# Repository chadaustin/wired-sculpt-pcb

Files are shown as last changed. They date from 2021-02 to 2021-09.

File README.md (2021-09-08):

# Design Files for Wired Sculpt Conversion Board

This repository contains the schematic and layout files for the [Microsoft Sculpt Wired Conversion Mod](https://chadaustin.me/2021/02/wired-sculpt/).

## Project Updates

### 2021-09-07

The rev4 board design is complete.

When I upgraded the 30-pin ribbon connector to one that fit better, it lowered the resistance to the LEDs. This caused me to burn the microcontroller on a test rev3 board by drawing too much current. So the question became: what values are appropriate for "maximum" brightness on both red and green. Today I found that, given a 5.15V VUSB, whatever resistance in the flex cable, and whatever voltage drop on the LEDs, 150 Ohms gives an even brightness on both red and green. Green draws about 15 mA and red about 10 mA, both within USB low-power spec and the current limits on the microcontroller.

I added an [outputs](outputs/) directory containing the different revisions, and gerber files and drill files generated for either PCBWay or OSH Park.

The biggest challenge right now is the chip shortage. Even some of the capacitors I chose are out of stock. The hardest component to acquire is the ESD protection IC: USBLC6-2SC6. The USBLC6-4SC6 is available, but it would require some tweaking to the PCB layout.

On the software side of things, I added an internal ring buffer for debugging the debouncer. It can be dumped to the HID debug channel by holding both shifts and pressing H. I am trying to figure out why, with my custom low-latency debouncer, sometimes "the" comes out as "theb". For anyone that isn't trying to optimize latency as much as me, you can just run with the default QMK debouncer, which I've never seen produce phantom keys.

### 2021-05-02

One thing that annoyed me about the previous board design was that neither LED was hooked up to a PWM-capable pin and that the green one couldn't be driven, since it wants -5V. I want both lights to work and both to be dimmable.

Rev3 includes a charge pump to produce -5V and two MOSFETs that allow switching the green cathode with PWM.

I also figured out how the Fn switch works: it's a resistor divider that toggles 47K pull-down on a pin with a permanent 1M pull-up. Rev3 includes said 1M pull-up, so the firmware can read the Fn switch's state.

Sadly, it looks like there were many arrangements of media keys on the Sculpt over the years, and most of the media keys have nonsensical icons with behavior that differs on each platform. I'll try to make at least volume and play/pause work.

The parts for board rev 3 arrived last week. Some adjustments were required due to the chip shortage, but it's not too bad. The microcontroller is still available at least.

I attempted assembly of one, and it worked fine, but I screwed up the red and green pins, so I cut some traces and bodged in some kynar wire.

Both lights work!

I have not tested PWM. I did observe that twice as much current is being drawn for each light as I expected. I fear 40 mA could burn out the lights, so I plan to measure an appropriate series resistor this week. It's possible I never had this problem before because I was using a worse-fitting ribbon connector previously. In the past, I always measured 100 Ohms on every pin, but never tested the new ribbon connector.

Also, it kind of sucks that the LED brightness is a function of USB voltage (anywhere between 4.6 V and 5.25 V), but I don't want to include a regulator...

Assembly took about five hours for one board. A lot of that was getting my desk set up. I imagine I could do three boards in ... eight? I think if I used a stencil, hot air assembly could go pretty quickly. Especially if I had a preheater like the MHP30.

A couple people have suggested I set up an Etsy, but if I properly priced in hours of my labor, it would get prohibitive. And I don't want to deal with returns and warranties.

Remaining items before I can say the board is done:
* Order a fourth PCB design with fixed green and red pins
* Include an 0603 resistor on each
* Fix the debouncer
* Add a media key QMK layer, enabled with the Fn switch.

### 2021-04-27

In February, I tried pushing latency further than QMK offers out of the box. I switched from the default debouncer to sym_eager_pk, but since then I've observed some false keydowns and occasionally a phantom keypress. It's common for "the" to produce "theb". (Note that I use the Dvorak key layout.) I haven't looked at the matrix, but it's clear some debouncing is needed on keydown.

I'm planning on writing a custom debouncer that requires at least two frames for a keydown to register and at least 10 ms for a keyup. Having never done AVR optimization, I am trying to get a [simavr](https://github.com/buserror/simavr) benchmark harness up to make sure I don't regress the scan rate.

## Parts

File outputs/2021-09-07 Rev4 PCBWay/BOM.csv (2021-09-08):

Component | Description | Part | References | Value | Footprint | Quantity Per PCB | Datasheet | Notes
1 | Unpolarized capacitor | C | C4 C5 C6 C9 | CL10A105KA8NNNC | C_0603_1608Metric | 4 | ~
2 | Unpolarized capacitor | C | C10 C11 C12 | CL10B104KB8NNNC | C_0603_1608Metric | 3 | https://media.digikey.com/pdf/Data%20Sheets/Samsung%20PDFs/CL05A104KA5NNNC.pdf
3 | Unpolarized capacitor | C | C7 C8 | CL10C160JB8NNNC | C_0603_1608Metric | 2 | ~
4 | Unpolarized capacitor | C | C1 | CL21A475KOFNNNE | C_0805_2012Metric | 1 | ~
5 | Unpolarized capacitor | C | C3 | CL21B103KBANNNC | C_0805_2012Metric | 1 | ~
6 | Unpolarized capacitor | C | C2 | CL21B104KACNNNC | C_0805_2012Metric | 1 | ~
7 | Light emitting diode | LED | D1 | 150080GS75000 | LED_0603_1608Metric_Castellated | 1 | ~
8 | USB Micro Type B connector | USB_B_Micro | J1 | 10103594-0001LF | USB_Micro-B_Amphenol_10103594-0001LF_Horizontal | 1 | https://www.amphenol-icc.com/media/wysiwyg/files/drawing/10118193.pdf
10 | Generic connector, single row, 01x30, script generated (kicad-library-utils/schlib/autogen/connector/) | Conn_01x30_Female | J2 | FFC3B07-30-T | TE_3-84952-0_1x30-1MP_P1.0mm_Horizontal | 1 | https://gct.co/files/specs/1.0mm-ffc-spec.pdf
11 | 0.115A Id, 60V Vds, N-Channel MOSFET, SOT-23 | 2N7002 | Q2 | 2N7002BK | SOT-23 | 1 | https://assets.nexperia.com/documents/data-sheet/2N7002BK.pdf
12 | -0.13A Id, -50V Vds, P-Channel MOSFET, SOT-23 | BSS84 | Q1 | BSS84AK,215 | SOT-23 | 1 | https://assets.nexperia.com/documents/data-sheet/BSS84AK.pdf
13 | Resistor, US symbol | R_US | R4 | ERJ-3EKF8873V | R_0603_1608Metric | 1 | ~
14 | Resistor, US symbol | R_US | R6 R9 R10 | ERJ-3GEYJ331V | R_0603_1608Metric | 3 | ~
15 | Resistor, US symbol | R_US | R1 R2 R7 | ERJ-PA3F22R0V | R_0603_1608Metric | 3 | ~
16 | Resistor, US symbol | R_US | R11 R12 | ERJ-PA3J151V | R_0603_1608Metric | 2 | ~ | Allows 10 mA. Maybe 100R would be fine. Measures at 15-17 mA.
17 | Resistor, US symbol | R_US | R3 R8 | ERJ-PA3J472V | R_0603_1608Metric | 2
18 | Resistor, US symbol | R_US | R5 | ERJ-PA3J473V | R_0603_1608Metric | 1 | ~
19 | Push button switch, generic, two pins | SW_Push | SW1 | FSMSM | SW_SPST_FSMSM | 1 | ~
20 | Generic connector, single row, 01x02, script generated (kicad-library-utils/schlib/autogen/connector/) | Conn_01x02_Female | SW2 | S2B-PH-K-S(LF)(SN) | JST_PH_S2B-PH-K_1x02_P2.00mm_Horizontal | 1 | https://www.jst-mfg.com/product/pdf/eng/ePH.pdf
21 | 16MHz, 128kB Flash, 8kB SRAM, 4kB EEPROM, USB 2.0, TQFP-64 | AT90USB1286-AU | U3 | AT90USB1286-AU | TQFP-64_14x14mm_P0.8mm | 1 | http://ww1.microchip.com/downloads/en/DeviceDoc/doc7593.pdf
22 | Switched capacitor inverter, inverts positive voltage +2.7 to +5.5V to negative, 200mA, SOT-23-6 | LM2776 | U2 | LM2776DBVT | SOT-23-6 | 1 | http://www.ti.com/lit/ds/symlink/lm2776.pdf
23 | Very low capacitance ESD protection diode, 2 data-line, SOT-23-6 | USBLC6-2SC6 | U1 | USBLC6-2SC6 | SOT-23-6 | 1 | https://www.st.com/resource/en/datasheet/usblc6-2.pdf
24 | Four pin crystal, GND on pins 2 and 4 | Crystal_GND24 | Y1 | TSX-3225 16.0000MF18X-AC0 | Crystal_SMD_3225-4Pin_3.2x2.5mm | 1 | https://www5.epsondevice.com/en/information/support/pdf/june_2018_psc_masterbook.pdf
Component Groups: | 24
Component Count: | 36
Fitted Components: | 36
Number of PCBs: | 1
Total components: | 36
Schematic Version:
Schematic Date:
PCB Variant: | udefault
BoM Date: | 2021-09-07 17:42
Schematic Source: | wired-sculpt.sch
KiCad Version: | Eeschema (5.1.8)-1

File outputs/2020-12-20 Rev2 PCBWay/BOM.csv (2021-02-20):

Id | Designator | Package | Quantity | Part # | Manufacturer | Notes
1 | U1 | TQFP-64_14x14mm_P0.8mm | 1 | AT90USB1286-AU | Atmel | Align dot on chip with dot on PCB (pin 1)
2 | J3 | IDC-Header_2x03_P2.54mm_Vertical | 1 | NOT FITTED
3 | R1,R3 | R_0603_1608Metric | 2 | ERJ-PA3F22R0V | Panasonic
4 | J4 | TE_3-84952-0_1x30-1MP_P1.0mm_Horizontal | 1 | 3-84952-0 | TE Connectivity
5 | C2,C3 | C_0603_1608Metric | 2 | 06035A160JAT2A | AVX Corporation
6 | C4 | C_0603_1608Metric | 1 | C0603C105K4RACTU | KEMET
7 | D1 | LED_0603_1608Metric_Castellated | 1 | 150080GS75000 | Wurth Electronik
8 | J1 | USB_Micro-B_Amphenol_10103594-0001LF_Horizontal | 1 | 10103594-0001LF | Amphenol ICC
9 | R2 | R_0603_1608Metric | 1 | ERJ-3EKF2200V | Panasonic
10 | R4,R5,R6 | R_0603_1608Metric | 3 | ERJ-3GEYJ331V | Panasonic
11 | SW1 | SW_SPST_FSMSM | 1 | FSMSM | TE Connectivity
12 | Y1 | Crystal_SMD_3225-4Pin_3.2x2.5mm | 1 | TSX-3225 16.0000MF18X-AC6 | Epson
13 | R8 | R_0603_1608Metric | 1 | ERJ-3EKF1001V | Panasonic
16 | C1 | C_1206_3216Metric | 1 | TAJA106K006RNJ | AVX Corporation
17 | C6,C7,C5 | C_0402_1005Metric | 3 | CL05A104KA5NNNC | Samsung
18 | R9 | R_0603_1608Metric | 1 | ERJ-3GEYJ331V | Panasonic
19 | U2 | SOT-23-6 | 1 | USBLC6-2SC6 | STMicroelectronics | Pin 1 is aligned with longer line on silkscreen, towards outside of board

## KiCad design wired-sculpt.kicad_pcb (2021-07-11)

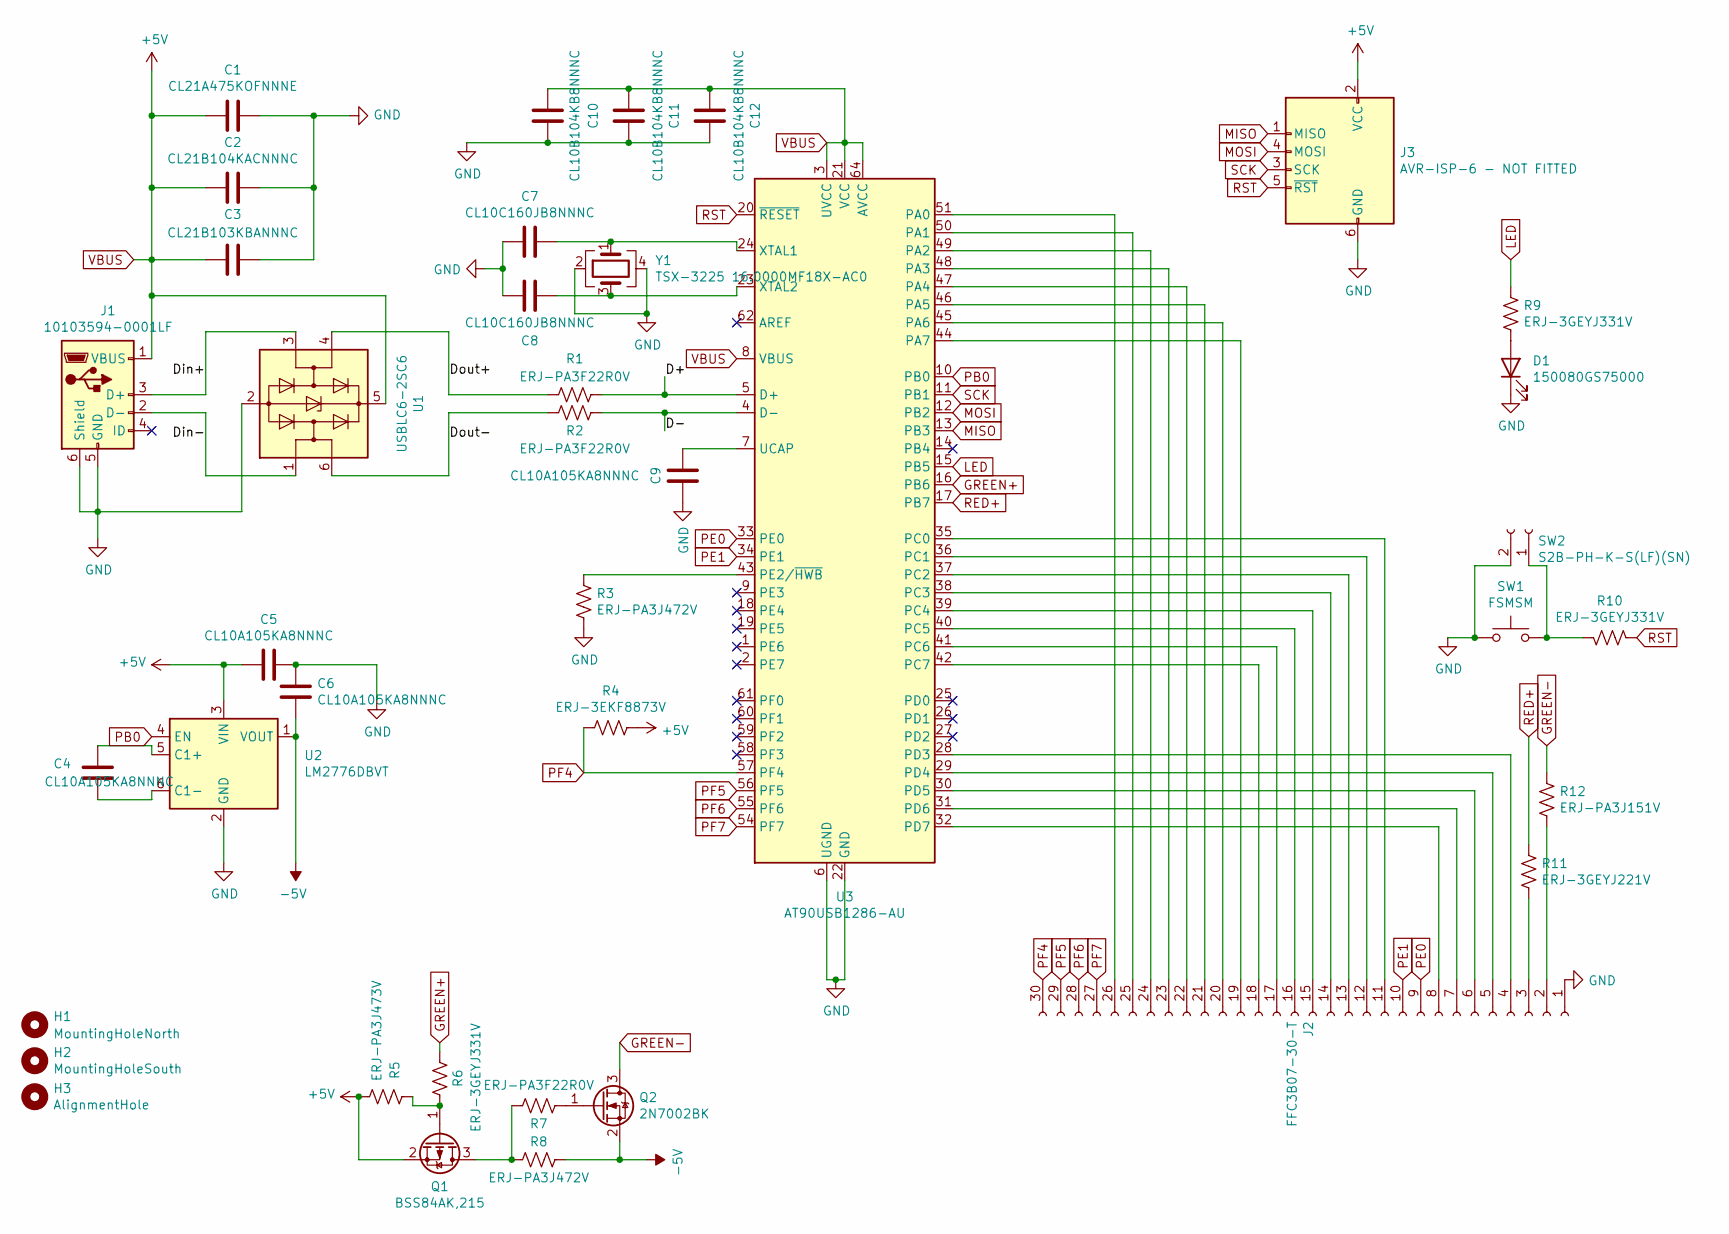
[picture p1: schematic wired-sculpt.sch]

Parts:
C1: CL21A475KOFNNNE; C_0805_2012Metric
C2: CL21B104KACNNNC; C_0805_2012Metric
C3: CL21B103KBANNNC; C_0805_2012Metric
C4, C5, C6, C9: CL10A105KA8NNNC; C_0603_1608Metric
C7, C8: CL10C160JB8NNNC; C_0603_1608Metric
C10, C11, C12: CL10B104KB8NNNC; C_0603_1608Metric
D1: 150080GS75000; LED_0603_1608Metric_Castellated
H1: MountingHoleNorth; MountingHole_2.2mm_M2
H2: MountingHoleSouth; MountingHole_2.2mm_M2
H3: AlignmentHole; MountingHole_2.7mm
J1: 10103594-0001LF; USB_Micro-B_Amphenol_10103594-0001LF_Horizontal
J2: FFC3B07-30-T; TE_3-84952-0_1x30-1MP_P1.0mm_Horizontal
J3: AVR-ISP-6 - NOT FITTED; IDC-Header_2x03_P2.54mm_Vertical
Q1: BSS84AK,215; SOT-23
Q2: 2N7002BK; SOT-23
R1, R2, R7: ERJ-PA3F22R0V; R_0603_1608Metric
R3, R8: ERJ-PA3J472V; R_0603_1608Metric
R4: ERJ-3EKF8873V; R_0603_1608Metric
R5: ERJ-PA3J473V; R_0603_1608Metric
R6, R9, R10: ERJ-3GEYJ331V; R_0603_1608Metric
R11: ERJ-3GEYJ221V; R_0603_1608Metric
R12: ERJ-PA3J151V; R_0603_1608Metric
SW1: FSMSM; SW_SPST_FSMSM
SW2: S2B-PH-K-S(LF)(SN); JST_PH_S2B-PH-K_1x02_P2.00mm_Horizontal
U1: USBLC6-2SC6; SOT-23-6
U2: LM2776DBVT; SOT-23-6
U3: AT90USB1286-AU; TQFP-64_14x14mm_P0.8mm
Y1: TSX-3225 16.0000MF18X-AC0; Crystal_SMD_3225-4Pin_3.2x2.5mm

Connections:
-5V: C6.2, Q2.2 (S), R8.1, U2.1 (VOUT)
/D+: R1.1, U3.5 (D+)
/D-: R2.1, U3.4 (D-)
/Din+: J1.3 (D+), U1.3 (I/O2)
/Din-: J1.2 (D-), U1.1 (I/O1)
/Dout+: R1.2, U1.4 (I/O2)
/Dout-: R2.2, U1.6 (I/O1)
GND: C1.1, C2.1, C3.1, C5.1, C6.1, C7.2, C8.2, C9.2, C10.1, C11.1, C12.1, D1.1 (K), J1.5 (GND), J1.6 (Shield), J2.1, J3.6 (GND), R3.2, SW1.1, SW2.2, U1.2 (GND), U2.2 (GND), U3.6 (UGND), U3.22 (GND), U3.53 (GND), U3.63 (GND), Y1.2, Y1.4
GREEN+: R6.2, U3.16 (PB6)
GREEN-: Q2.3 (D), R12.1
LED: R9.1, U3.15 (PB5)
MISO: J3.1 (MISO), U3.13 (PB3)
MOSI: J3.4 (MOSI), U3.12 (PB2)
unnamed: C4.1, U2.5 (C1+)
unnamed: C4.2, U2.6 (C1-)
unnamed: C7.1, U3.24 (XTAL1), Y1.1
unnamed: C8.1, U3.23 (XTAL2), Y1.3
unnamed: C9.1, U3.7 (UCAP)
unnamed: D1.2 (A), R9.2
unnamed: J2.2, R12.2
unnamed: J2.3, R11.2
unnamed: J2.4, U3.28 (PD3)
unnamed: J2.5, U3.29 (PD4)
unnamed: J2.6, U3.30 (PD5)
unnamed: J2.7, U3.31 (PD6)
unnamed: J2.8, U3.32 (PD7)
unnamed: J2.11, U3.35 (PC0)
unnamed: J2.12, U3.36 (PC1)
unnamed: J2.13, U3.37 (PC2)
unnamed: J2.14, U3.38 (PC3)
unnamed: J2.15, U3.39 (PC4)
unnamed: J2.16, U3.40 (PC5)
unnamed: J2.17, U3.41 (PC6)
unnamed: J2.18, U3.42 (PC7)
unnamed: J2.19, U3.44 (PA7)
unnamed: J2.20, U3.45 (PA6)
unnamed: J2.21, U3.46 (PA5)
unnamed: J2.22, U3.47 (PA4)
unnamed: J2.23, U3.48 (PA3)
unnamed: J2.24, U3.49 (PA2)
unnamed: J2.25, U3.50 (PA1)
unnamed: J2.26, U3.51 (PA0)
unnamed: Q1.1 (G), R5.1, R6.1
unnamed: Q1.3 (D), R7.2, R8.2
unnamed: Q2.1 (G), R7.1
unnamed: R3.1, U3.43 (PE2/~HWB)
unnamed: R10.2, SW1.2, SW2.1
PB0: U2.4 (EN), U3.10 (PB0)
PE0: J2.9, U3.33 (PE0)
PE1: J2.10, U3.34 (PE1)
PF4: J2.30, R4.2, U3.57 (PF4)
PF5: J2.29, U3.56 (PF5)
PF6: J2.28, U3.55 (PF6)
PF7: J2.27, U3.54 (PF7)
RED+: R11.1, U3.17 (PB7)
RST: J3.5 (~RST), R10.1, U3.20 (~RESET)
SCK: J3.3 (SCK), U3.11 (PB1)
VBUS: C1.2, C2.2, C3.2, C5.2, C10.2, C11.2, C12.2, J1.1 (VBUS), J3.2 (VCC), Q1.2 (S), R4.1, R5.2, U1.5 (VBUS), U2.3 (VIN), U3.3 (UVCC), U3.8 (VBUS), U3.21 (VCC), U3.52 (VCC), U3.64 (AVCC)

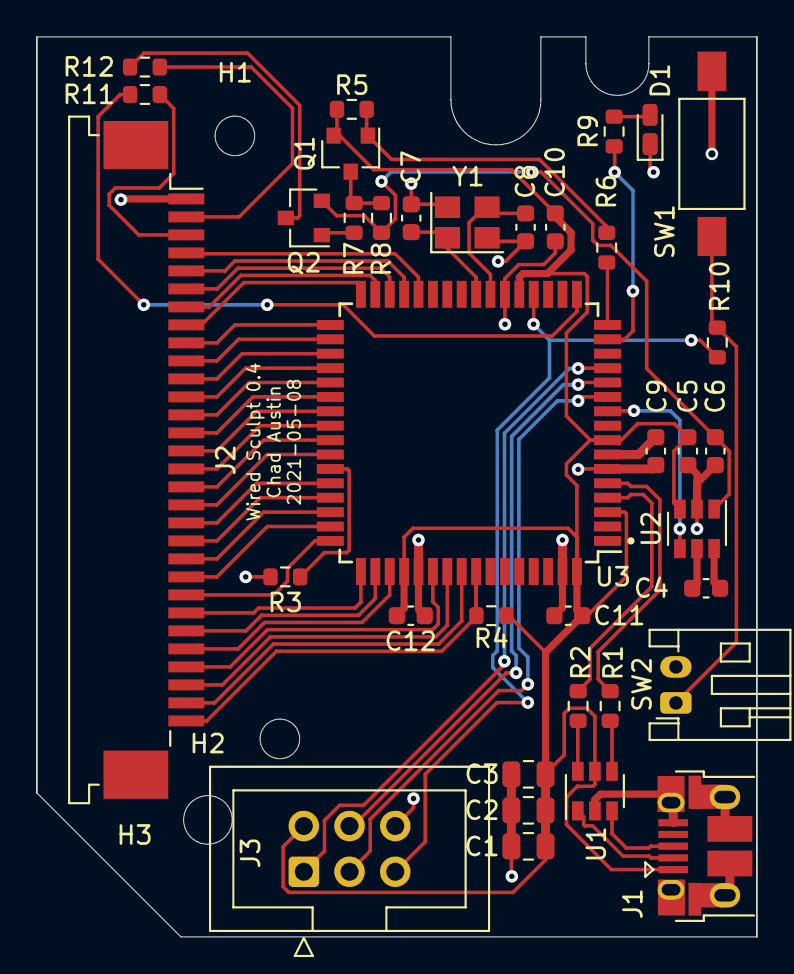
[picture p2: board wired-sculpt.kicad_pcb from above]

Board: 2 copper layers, 40.0 x 50.0 mm, 39 parts (0 on the bottom side), 58 nets.

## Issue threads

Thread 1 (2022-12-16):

License?

cberner, 2022-12-16:
Hi, thanks for the great blog post! I'm interested in using your PCB design to convert my Sculpt keyboard to be wired. What are the licensing terms of these PCB files?

chadaustin, 2022-12-23:
Hi Chris! The license is whatever you want. :) Feel free to use them as you wish. I'll try to add an explicit COPYRIGHT.

cberner, 2022-12-23:
Awesome, thanks!

Closed 2022-12-23.

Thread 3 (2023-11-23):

How to flash the QMK?

sofa-li, 2023-11-23:
I'm very excited to see your git, my Sculpt keyboard's receiver is lost, I've been thinking about how to restore it, I really want to replicate your project, but I'm a beginner, I want to know how to flash QMK after I make such a circuit board, thank you very much for your work!

chadaustin, 2023-11-24:
Once the board is made and installed, flashing is pretty easy. I forget the command offhand, but it's the standard `make $keyboard:flash` command from my QMK fork. I can help when you get that far.

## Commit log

2021-02-20 0.2 design files
    [BOM.csv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]
2021-04-18 WIP: checkpoint work on rev 3 of the schematic and layout
    [wired-sculpt.kicad_pcb, wired-sculpt.sch]
2021-04-18 renumber the references
    [wired-sculpt.kicad_pcb, wired-sculpt.sch]
2021-04-19 Move a trace and generate gerbers for Apr 18
    [BOM.csv, Bom_DigiKey_8567632.csv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]
2021-05-02 fit the schematic on US Letter paper instead of A4
    [wired-sculpt.sch]
2021-05-03 Fix Green- and Red+ pins which were backwards. :(
    [wired-sculpt.kicad_pcb, wired-sculpt.sch]
2021-05-09 add two resistors for the LEDs: this ribbon cable connector must have lower resistance
    [wired-sculpt.kicad_pcb, wired-sculpt.sch]
2021-05-09 chip shortage part substitutions
    [wired-sculpt.sch]
2021-07-11 change resistor values for LEDs
    [wired-sculpt.kicad_pcb, wired-sculpt.sch]
2021-09-07 set red and green current-limiting resistors to 150R
    [wired-sculpt.sch]
2021-09-07 add 0.4 revision board gerbers for osh park
    [BOM 05-08.csv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]
2021-09-08 move outputs into named directories
    [BOM 05-08.csv, BOM.csv, Bom_DigiKey_8567632.csv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]
2021-09-08 add a rev4 output for PCBWay
    [BOM.csv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]
